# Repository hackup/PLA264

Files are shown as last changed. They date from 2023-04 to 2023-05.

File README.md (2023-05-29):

# PLA264

The PLA264 is a replacement for the MOS 251641-02 PLA chip used in Commodore's TED-based 8-bit computers, the C16, C116, and Plus/4. It is an alternative layout to the [PLA16V8](https://www.freepascal.org/~daniel/c16pla/). Like the original, it is based on the GAL16V8 and it requires the same JED file for programming. Unlike the original, when properly assembled, it is small enough to actually fit into the case of a Commodore Plus/4 without issues.

See my [blog post](https://www.hackup.net/2023/05/how-to-lower-your-pla-the-pla264/) for more details.

There is no warranty whatsoever. **USE AT YOUR OWN RISK!**.

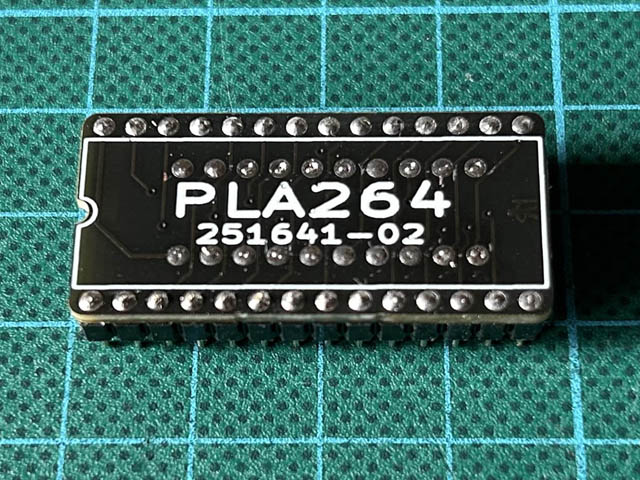
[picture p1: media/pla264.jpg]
PLA264 Rev.0


## License


This work is licensed under a
[Creative Commons Attribution-NonCommercial-ShareAlike 4.0 International License](http://creativecommons.org/licenses/by-nc-sa/4.0/).

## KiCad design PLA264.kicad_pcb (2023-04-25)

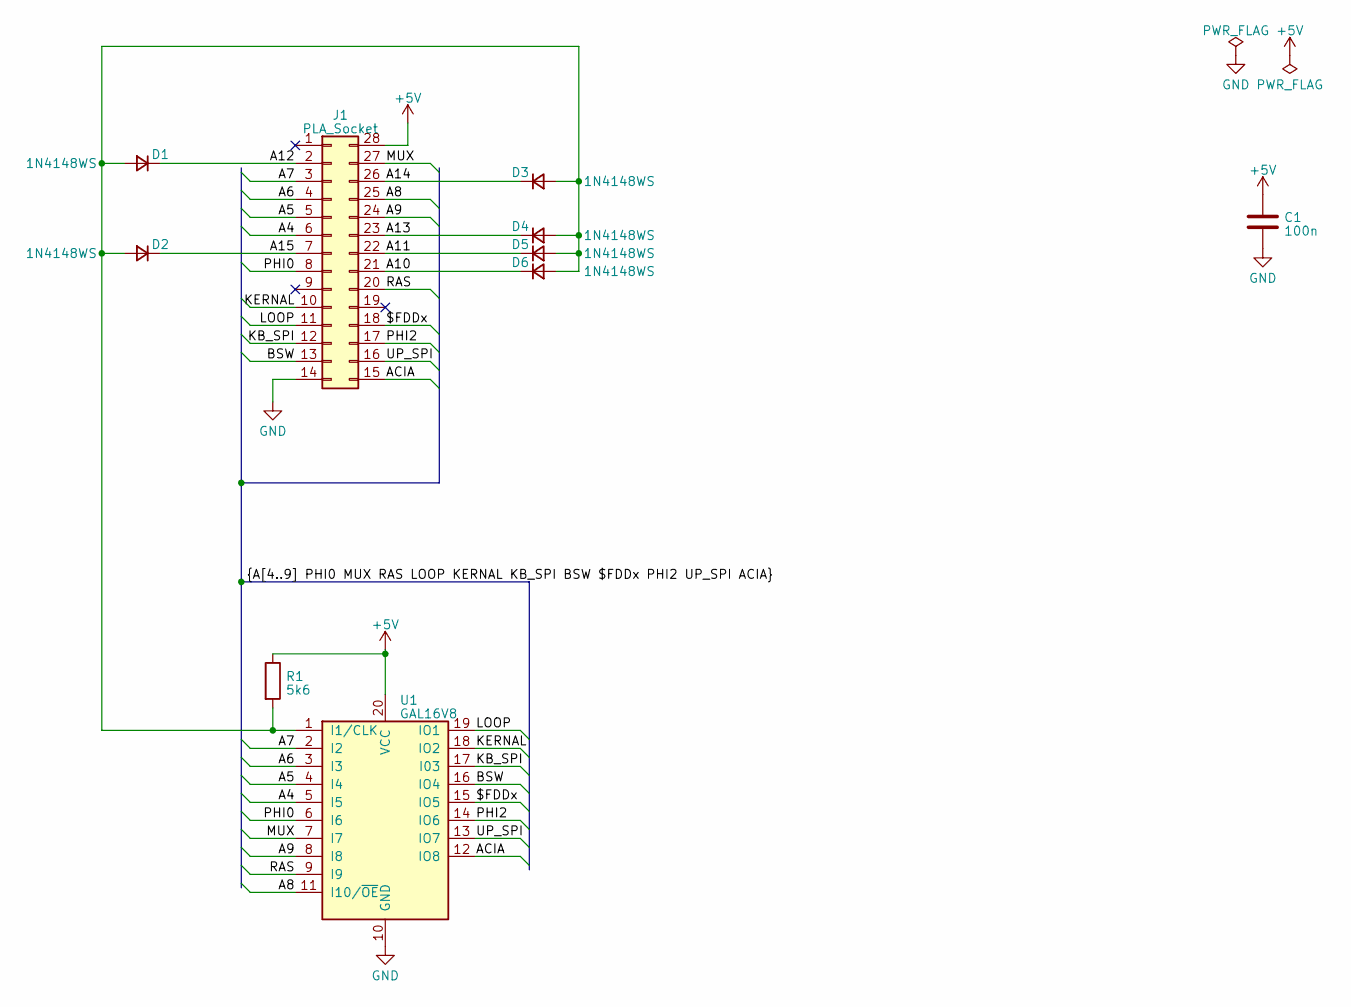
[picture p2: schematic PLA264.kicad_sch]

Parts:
C1: 100n; C_0603_1608Metric; LCSC C14663
D1, D2, D3, D4, D5, D6: 1N4148WS; D_SOD-323; LCSC C2128
J1: PLA_Socket; DIP-28_W15.24mm
R1: 5k6; R_0603_1608Metric; LCSC C23189
U1: GAL16V8; DIP-20_W7.62mm

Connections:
+5V: C1.1, J1.28, R1.1, U1.20 (VCC)
/$FDDx: J1.18, U1.15 (IO5)
/A4: J1.6, U1.5 (I5)
/A5: J1.5, U1.4 (I4)
/A6: J1.4, U1.3 (I3)
/A7: J1.3, U1.2 (I2)
/A8: J1.25, U1.11 (I10/~OE)
/A9: J1.24, U1.8 (I8)
/A10: D6.1 (K), J1.21
/A11: D5.1 (K), J1.22
/A12: D1.1 (K), J1.2
/A13: D4.1 (K), J1.23
/A14: D3.1 (K), J1.26
/A15: D2.1 (K), J1.7
/ACIA: J1.15, U1.12 (IO8)
/BSW: J1.13, U1.16 (IO4)
/KB_SPI: J1.12, U1.17 (I03)
/KERNAL: J1.10, U1.18 (IO2)
/LOOP: J1.11, U1.19 (IO1)
/MUX: J1.27, U1.7 (I7)
/PHI0: J1.8, U1.6 (I6)
/PHI2: J1.17, U1.14 (IO6)
/RAS: J1.20, U1.9 (I9)
/UP_SPI: J1.16, U1.13 (IO7)
GND: C1.2, J1.14, U1.10 (GND)
unnamed: D1.2 (A), D2.2 (A), D3.2 (A), D4.2 (A), D5.2 (A), D6.2 (A), R1.2, U1.1 (I1/CLK)

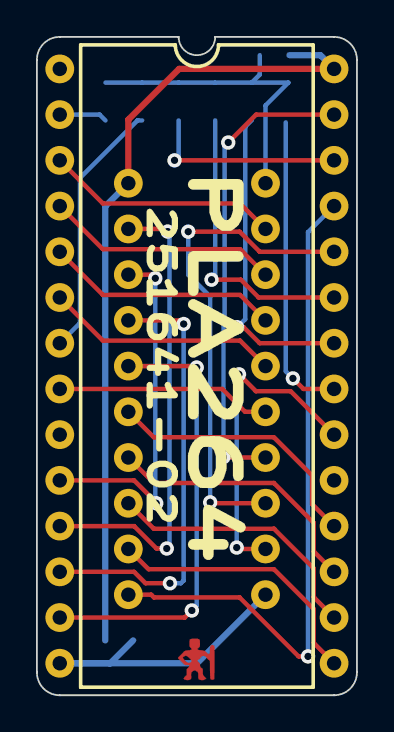
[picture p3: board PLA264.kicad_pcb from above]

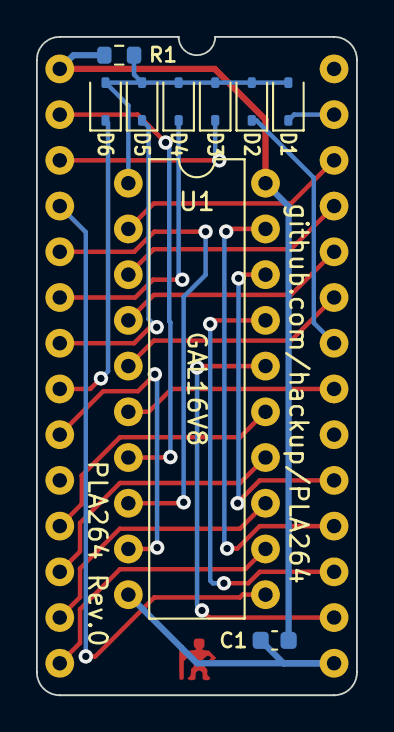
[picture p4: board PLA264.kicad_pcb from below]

Board: 2 copper layers, 17.8 x 36.6 mm, 10 parts (9 on the bottom side), 26 nets.

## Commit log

2023-04-25 Initial import.
    [PLA264.kicad_pcb, PLA264.kicad_sch]
2023-04-25 Revised layout.
    [PLA264.kicad_pcb, PLA264.kicad_sch]
2023-04-25 Cleaning up.
    [PLA264.kicad_pcb, PLA264.kicad_sch]
2023-04-25 Preparing for Gerber export.
    [PLA264.kicad_pcb, PLA264.kicad_sch]
